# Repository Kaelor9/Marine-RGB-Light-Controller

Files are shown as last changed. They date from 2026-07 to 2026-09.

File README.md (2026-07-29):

<p align="center">
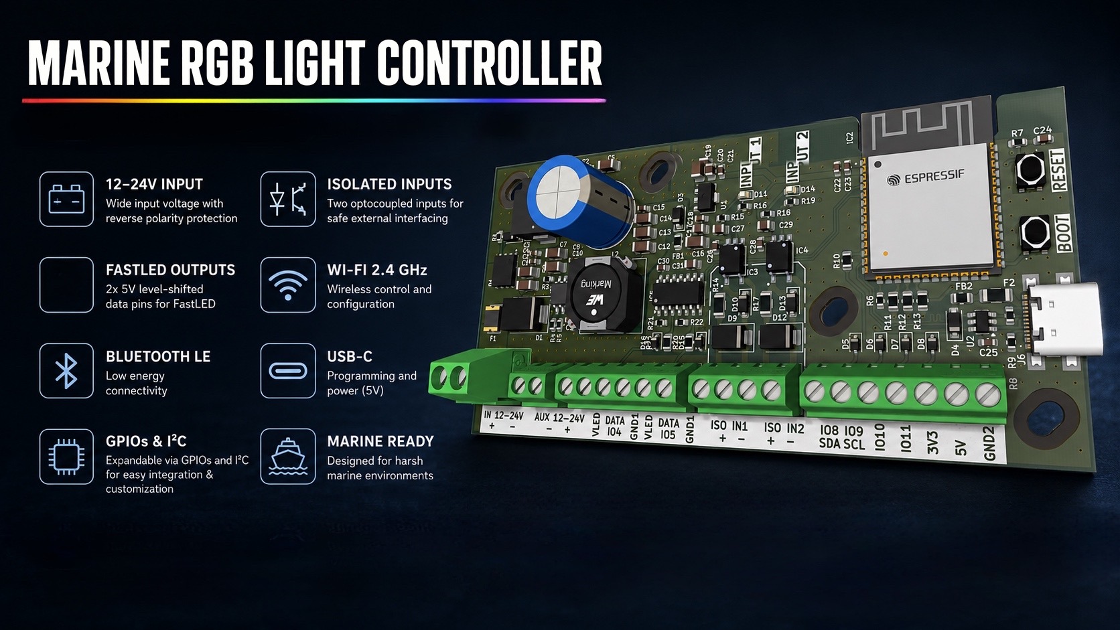
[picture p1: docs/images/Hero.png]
Marine RGB Light Controller
  
</p>

<h1 align="center">Marine RGB Light Controller</h1>

<p align="center">
  Professional ESP32-S3 controller for addressable RGB LED installations in marine, automotive and industrial environments.
</p>

<p align="center">
  
  
  
  
  
</p>

<p align="center">
  <a href="https://kaelor9.github.io/Marine-RGB-Light-Controller/">
    
  </a>
</p>

---

## About

The **Marine RGB Light Controller** is a custom-designed ESP32-S3 controller developed for reliable operation in demanding electrical environments.

Unlike generic ESP32 development boards, it integrates protected power electronics, optically isolated inputs, dual level-shifted LED outputs and dedicated expansion interfaces into a single compact PCB.

Originally designed for marine lighting systems, the controller is equally suited for automotive, off-road, RV, architectural and industrial LED installations.

---

## Why this controller?

Most ESP32 development boards are intended for prototyping and require additional external circuitry before they are suitable for real-world installations.

The Marine RGB Light Controller integrates the essential hardware needed for reliable field deployment:

- Protected 12–24V power input
- Reverse polarity protection
- TVS surge suppression
- Optically isolated inputs
- Dual 5V LED data outputs
- USB-C programming
- GPIO & I²C expansion
- Compact installation-ready PCB

This significantly reduces external wiring while improving robustness and long-term reliability.

---

## Key Features

- ⚡ Protected 12–24V DC controller input
- 🔋 Direct VIN pass-through LED power output
- 🌈 Two independent 5V level-shifted LED data outputs
- 🔒 Two high-speed optically isolated digital inputs
- 📡 Wi-Fi & Bluetooth LE
- 🔌 USB-C programming
- 🔧 GPIO & I²C expansion
- 🛡 TVS, fuse and reverse polarity protection
- ⚓ Designed for harsh electrical environments

---

## Applications

The controller is suitable for a wide range of professional LED installations, including:

- ⚓ Marine lighting
- 🚙 Automotive lighting
- 🏕 Camper & RV installations
- 🏭 Industrial automation
- 🏡 Architectural lighting
- 💡 Custom RGB LED projects

---

## Hardware

<p align="center">
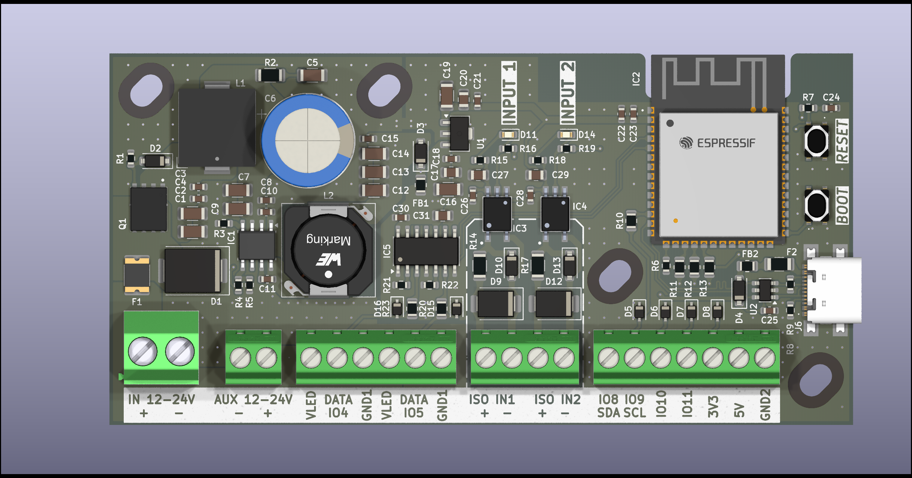
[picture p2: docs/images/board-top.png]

</p>

The PCB integrates everything required for a professional LED controller:

- ESP32-S3-WROOM-1-N8R8
- High-efficiency buck converter
- Low-noise 3.3V LDO
- USB-C programming interface
- Dual 5V level shifters
- High-speed optocouplers
- Protected controller power supply
- GPIO & I²C expansion
- Dedicated LED power distribution

---

## Technical Specifications

| Feature | Specification |
|---|---|
| MCU | ESP32-S3-WROOM-1-N8R8 |
| Flash | 8 MB |
| PSRAM | 8 MB |
| Input Voltage | 12–24V DC |
| Controller Protection | Fuse + Reverse Polarity + TVS |
| LED Supply | Direct VIN Pass-through |
| LED Outputs | 2 × 5V Logic (Level Shifted) |
| Digital Inputs | 2 × Optically Isolated |
| Wireless | Wi-Fi 2.4 GHz + Bluetooth LE |
| USB | USB-C |
| Expansion | GPIO + I²C |

---

## Pinout

<p align="center">
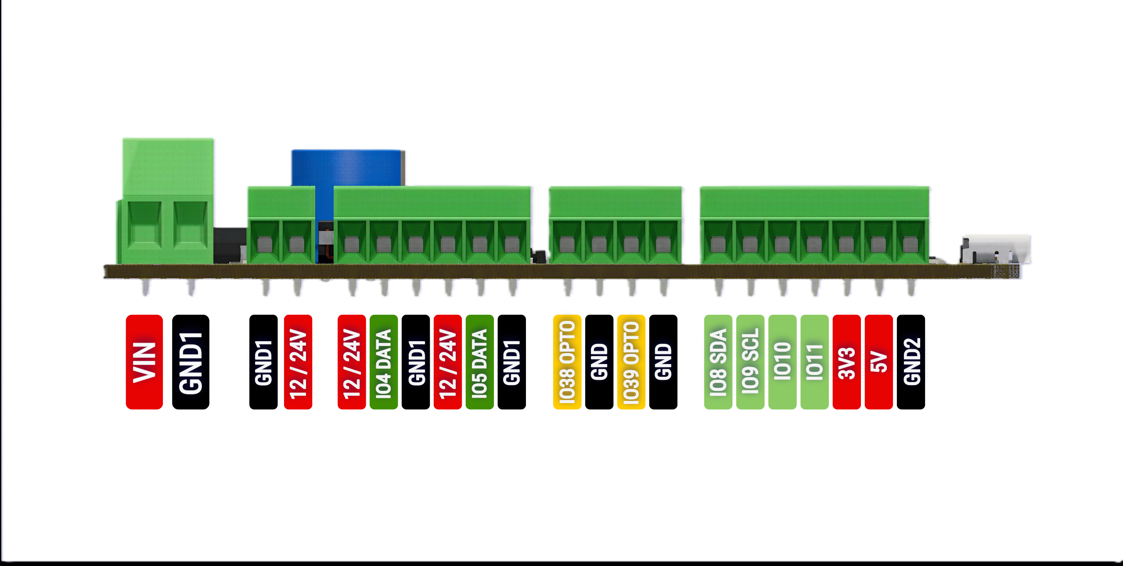
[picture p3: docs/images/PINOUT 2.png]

</p>

| Connection | Function |
|---|---|
| VIN | 12–24V DC Input |
| AUX Power | Direct VIN Pass-through |
| DATA 1 | 5V LED Data Output |
| DATA 2 | 5V LED Data Output |
| ISO IN1 | Optically Isolated Input |
| ISO IN2 | Optically Isolated Input |
| SDA / SCL | I²C Expansion |
| IO8 / IO9 | GPIO Expansion |
| IO10 / IO11 | GPIO Expansion |
| 3V3 | 3.3V Output |
| 5V | 5V Output |
| GND | Ground |

---

## Gallery

<p align="center">

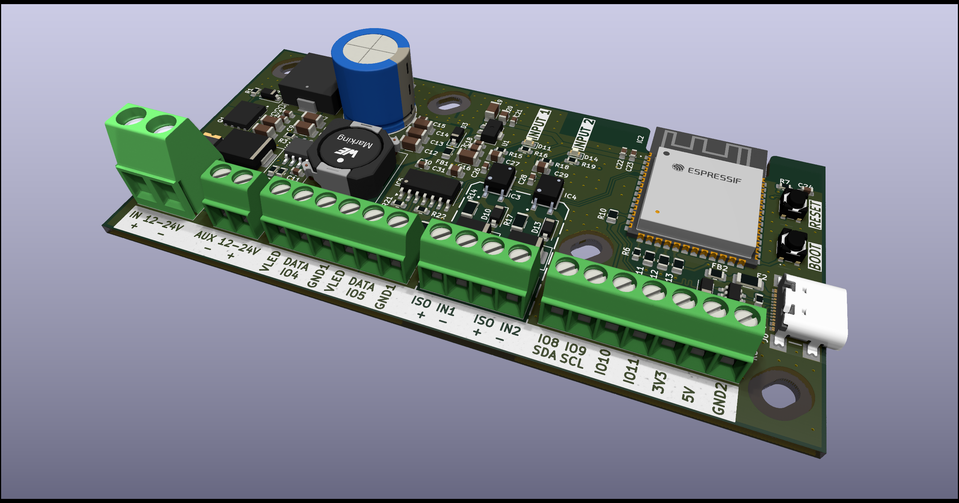
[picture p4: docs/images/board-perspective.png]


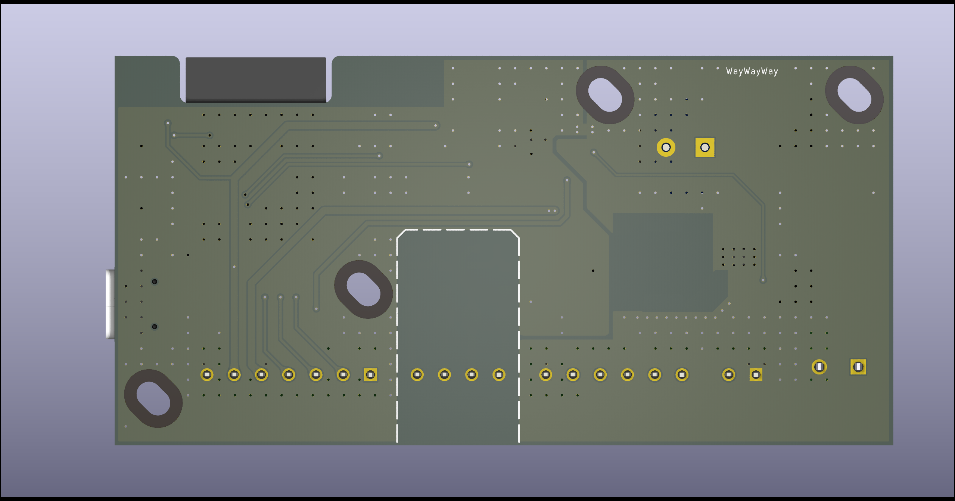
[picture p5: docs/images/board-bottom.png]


</p>

---

## Software

The firmware is developed for the ESP32-S3 using the Arduino framework and is designed around a modern, responsive web interface.

Configuration is performed directly from any web browser without requiring additional software. The modular firmware architecture allows new LED effects and features to be added easily.

Current and planned features include:

- Modern Web UI
- RGB Color Picker
- Brightness Control
- LED Effects
- Wi-Fi Configuration
- mDNS Support
- OTA Firmware Updates
- FastLED Support
- Configuration Storage

---

## Repository Structure

```text
.
├── docs/
│   ├── images/
│   ├── hardware.md
│   ├── software.md
│   └── fabrication.md
│
├── firmware/
│   └── Marine_RGB_Controller/
│
├── hardware/
│   ├── kicad/
│   ├── fabrication/
│   └── 3d/
│
├── site/
│
├── LICENSE
└── README.md
```

---

## Documentation

Project documentation is located inside the **docs** directory.

Available documentation includes:

- Hardware Design
- Power Supply
- LED Outputs
- Optically Isolated Inputs
- Pinout
- Firmware
- Fabrication
- Getting Started

---

## Important Information

> [!IMPORTANT]
>
> The **LED power output is a direct pass-through of the input supply voltage.**
>
> - LED VOUT = VIN
> - The LED supply is **not reverse polarity protected**
> - The LED supply is **not fused**
> - Only the controller electronics are protected by the onboard fuse, TVS diode and reverse polarity protection
> - External protection should be added where required by the installation

---

## Project Status

| Hardware | Firmware | Documentation |
|---|---|---|
| ✅ Revision 1 Complete | 🚧 In Development | 🚧 In Progress |

---

## Roadmap

### Hardware

- [x] Hardware Revision 1
- [x] Protected Power Supply
- [x] USB-C Programming
- [x] Dual LED Outputs
- [x] Optically Isolated Inputs

### Firmware

- [ ] Complete Web Interface
- [ ] OTA Updates
- [ ] MQTT Support
- [ ] Home Assistant Integration
- [ ] Additional LED Effects
- [ ] Configuration Backup & Restore

---

## License

This project is proprietary.

Copyright © 2026 Anders Merrild

All rights reserved.

No permission is granted to copy, modify, distribute, manufacture, publish, sublicense or use any part of this project without prior written permission from the copyright holder.

See the [LICENSE](LICENSE) file for full terms.

---

<p align="center">

Designed and developed by <strong>Kaelor9</strong>

<br>

ESP32 • Marine Electronics • Professional RGB Lighting Controller

</p>

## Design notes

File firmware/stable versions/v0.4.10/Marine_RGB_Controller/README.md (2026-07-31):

# Prism Firmware — v0.4.3

Firmware for the Marine RGB Light Controller hardware.

## Input configuration

The isolated input pins are fixed by the PCB:

- Input 1 = GPIO38
- Input 2 = GPIO39

Users do not enter GPIO numbers in the app. Under **Settings → Advanced settings**, both inputs can be enabled or disabled and assigned an action. Input enable changes take effect immediately.

Available actions include cycle preset colors, toggle power / hold to dim, next or previous effect, brightness up or down, warm white, and red, green or blue scenes.

## Light interface

- Embedded 6 × 60° perceptual hue wheel
- Hue-wheel selector remains fully inside the wheel
- Brightness slider integrated into the selected-color tile
- Static color, Rainbow Flow, Color Fade, Disco and Sparkle
- Smooth static transitions at approximately 60 FPS
- Warm-white compensation limited to the calibrated warm-white area

## Configuration notes

Changing LED count, color order or mDNS hostname requires a controller restart. Input enable settings apply immediately.

## Other included features

- Wi-Fi provisioning
- mDNS
- PWA name: Prism
- Embedded app logo
- OTA update page at `/update`

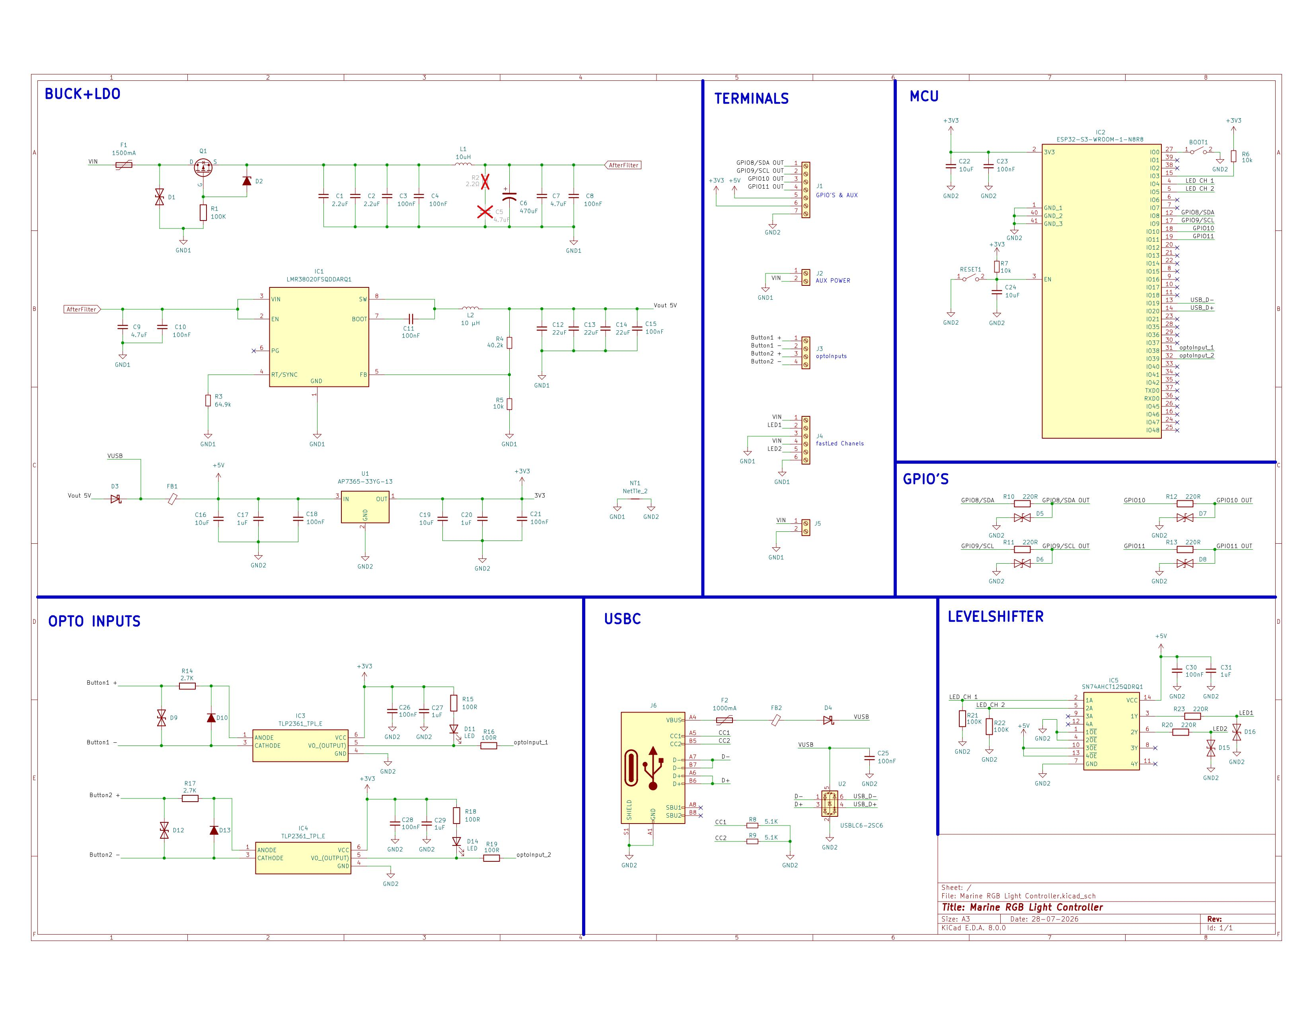
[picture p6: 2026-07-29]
docs/images/schematic.png

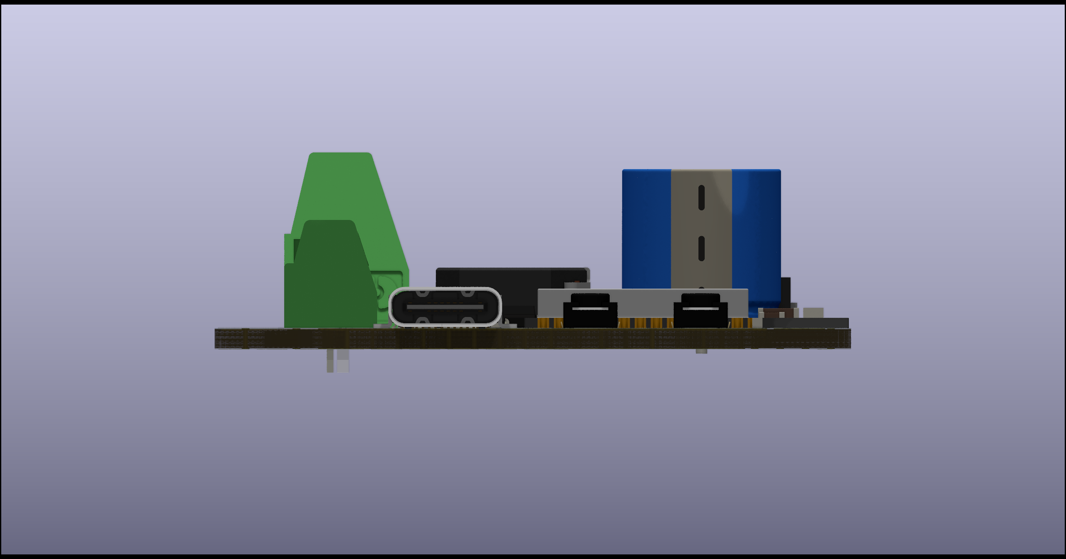
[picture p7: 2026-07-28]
docs/images/board-side-usb.png

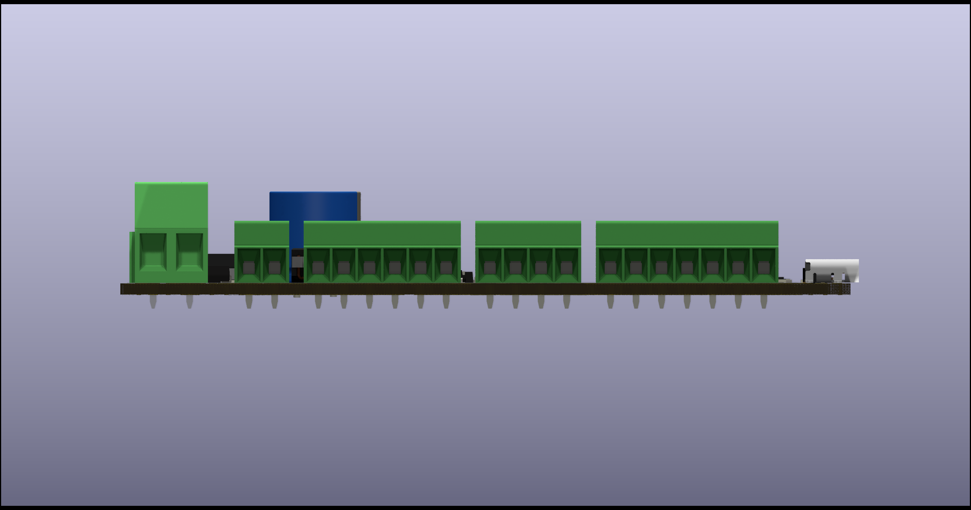
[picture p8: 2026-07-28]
docs/images/board-side-connectors.png

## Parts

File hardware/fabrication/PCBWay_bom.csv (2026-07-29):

Designator | Quantity | Value | Footprint | Package | MPN | DNP | Mount_Type | Description | Mfr. | Mfr. No: | Voltage Rating VDC | URL | Height | Mouser Part Number | Mouser Price/Stock | Manufacturer_Name | Mfr:
 | 1 |  |  |  |  |  | tht
BOOT, RESET | 2 | ~ | SW [PTS810SJM250SMTRLFS] |  |  |  | smt | Single Pole Single Throw (SPST) switch | PTS810SJM250SMTR LFS | C&K
C1, C2 | 2 | 2.2uF | C_1206_3216Metric |  |  |  | smt | Unpolarized capacitor, small symbol | Wurth Elektronik | 885012208124 | 100V
C10, C11, C15, C18, C21, C23, C25, C26, C28, C3, C30, C4, C8 | 13 | 100nF | C_0603_1608Metric |  |  |  | smt | [C4,C8]Unpolarized capacitor, small symbol; [C30]Multilayer Ceramic Capacitors MLCC - SMD/SMT 0603 MLCC X7R 0.1 uF, +/- 10% 50 V T&R MG | [C4,C8]Murata Electronics; [C30]Walsin | [C4,C8]GRM188R72A104KA35D; [C30]MG18B104K500CT | [C4,C8]100V; [C30]50V
C12, C13, C14 | 3 | 22uF | C_1206_3216Metric |  |  |  | smt | Multilayer Ceramic Capacitors MLCC - SMD/SMT PLEASE SEE SUGGESTED ALTERNATE MSASE105SC6105MFNA01 | TAIYO YUDEN | EMK316BB7226ML-T | 16V
C16, C19 | 2 | 10uF | C_1206_3216Metric |  |  |  | smt | Multilayer Ceramic Capacitors MLCC - SMD/SMT CGA 1206 16V 10uF X7R 10% AEC-Q200 | TDK | CGA5L1X7R1C106K160AC | 16V
C17, C20, C27, C29, C31 | 5 | 1uF | C_0805_2012Metric |  |  |  | smt | [C17,C20]Unpolarized capacitor, small symbol; [C27,C29]Multilayer Ceramic Capacitors MLCC - SMD/SMT KAM21KR71H105KL NEW GLOBAL PN 50V 1uF X7 A 581-KAM21KR71H105KL; [C31]Multilayer Ceramic Capacitors MLCC - SMD/SMT Automotive MLCC 1uF, 10%, X7R, 50VDC | [C17,C20]Samsung Electro-Mechanics; [C27,C29,C31]KYOCERA AVX | [C17,C20]CL21B105KAFNFNE; [C27,C29]08055C105K4T4A; [C31]KAM21KR71H105KL | [C17,C20]25V; [C27,C29,C31]50V
C22, C24 | 2 | 10uF | C_0603_1608Metric |  |  |  | smt | Multilayer Ceramic Capacitors MLCC - SMD/SMT 10 uF 35 VDC 20% 0603 X5R | Murata Electronics | GRM188R6YA106MA73D | 35V
C5 | 1 | 4.7uF | C_1206_3216Metric |  |  | Yes | smt | Unpolarized capacitor, small symbol | TDK | CGA5L1X7R2A475K160AC | 100V
C6 | 1 | 470uF | CP_Radial_D12.5mm_P5.00mm |  |  |  | tht | Aluminium Electrolytic Capacitors - Radial Leaded 470uF 63V 20% 12.5 x 25 | Vishay | MAL217058471E3 | 63V | https://www.mouser.dk/ProductDetail/Vishay -BC-Components/MAL217058471E3?qs=sGAEpiMZZ MvwFf0viD3Y3a3yb5D6sPUge%2FhbHmEvBGTt46%2F Okru66g%3D%3D
C7, C9 | 2 | 4.7uF | C_1206_3216Metric |  |  |  | smt | Unpolarized capacitor, small symbol | TDK | CGA5L1X7R2A475K160AC | 100V
D1 | 1 | D_TVS | D_SMC |  |  |  | smt | ESD Protection Diodes / TVS Diodes 33volts 5uA 28.1 Amps Uni-Dir | Bourns | SMCJ33A
D10, D13 | 2 | ~ | D_SOD-123 |  |  |  | smt | Small Signal Switching Diodes DIODE SWITCHING 100V 150mA 500mW SOD-123 | Comchip Technology | 1N4148W-HF
D11, D14 | 2 | LED | LED_0603_1608Metric |  |  |  | smt | Single Colour LEDs GREEN WATER CLEAR | Kingbright | APT1608SGC
D12, D9 | 2 | D_TVS | D_SMB |  |  |  | smt | ESD Protection Diodes / TVS Diodes 600W 33V 5% Bi-Directional | Littelfuse | SMBJ33CA
D15, D16, D5, D6, D7, D8 | 6 | SD05_SOD323 | D_SOD-323 |  |  |  | smt | ESD Protection Diodes / TVS Diodes 5V 450W 30A BiDirectional | Littelfuse | SD05C-01FTG
D2 | 1 | D_Zener_Filled | D_SOD-123 |  |  |  | smt | Zener diode, filled shape | Diodes Incorporated | BZT52C12-7-F
D3, D4 | 2 | D_Schottky | D_SOD-123 |  |  |  | smt | Schottky Diodes & Rectifiers RECT 40V 1A SM SCHOTTKY | Nexperia | PMEG40T10ERX
F1 | 1 | 1.5A | Fuse_1812_4532Metric |  |  |  | smt | Resettable Fuses - PPTC PTC RESETTABLE 0.75A 30V SMD 1812 | Bourns | MF-MSMF075/30-2 | 30 VDC | https://www.mouser.dk/ProductDetail/Bourns/MF-MSMF075-30-2?qs=3eVyCPG4fwndJ0FQwwSDlA%3D%3D
F2 | 1 | Polyfuse | Fuse_1206_3216Metric |  |  |  | smt | Resettable Fuses - PPTC 1206 Resettable SMD PPTC 0.50A/16V | Bourns | MF-NSMF050/16X-2
FB1 | 1 | BLM21PG600SN1D | R_0805_2012Metric |  |  |  | smt | Ferrite Beads 60 OHM 25% Alternate Sizing Guide Below | Murata Electronics | BLM21PG600SN1D
FB2 | 1 | FerriteBead_Small | R_0805_2012Metric |  |  |  | smt | Ferrite Beads 22 OHM 25% Alternate Sizing Guide Below | Murata Electronics | BLM21PG220SN1D
IC1 | 1 | C | Texas_R-PDSO-G8_EP2.95x4.9mm_Mask2.4x3.1mm |  |  |  | smt | Switching Voltage Regulators Automotive SIMPLE SWITCHER power converter 4.2-V to 80-V, 2-A, synchronous buck converter | Texas Instruments | LMR38020FSQDDARQ1 | 80V
IC2 | 1 | ESP32-S3-WROOM-1-N8R8 | ESP32S3WROOM1N8R8 |  | ESP32-S3-WROOM-1-N8R8 |  | smt | WiFi Modules - 802.11 (Engineering Samples Only) SMD Module, ESP32-S3R8 with 8 MB Octal PSRAM Die, 8 MB Quad SPI flash, PCB Antenna |  |  |  |  | 3.25 | 356-EP32S3WROOM1N8R8 | https://www.mouser.co.uk/ProductDetail/Espressif-Systems/ESP32-S3-WROOM-1-N8R8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 | Espressif Systems
IC3, IC4 | 2 | TLP2361_TPL,E | SOIC-6 |  | TLP2361(TPL,E |  | smt | High Speed Optocouplers X36 PB Photocoupler Lo I/P cur 125 degC |  |  |  |  |  | 757-TLP2361(TPLE | https://www.mouser.co.uk/ProductDetail/Toshiba/TLP2361TPLE?qs=HVbQlW5zcXUn%252BfokbzIatg%3D%3D | Toshiba
IC5 | 1 | SN74AHCT125QDRQ1 | SOIC-14_3.9x8.7mm_P1.27mm |  | SN74AHCT125QDRQ1 |  | smt | Automotive Catalog Quadruple Bus Buffer Gates With 3-State Outputs |  |  |  |  | 1.75 | 595-SN74AHCT125QDRQ1 | https://www.mouser.co.uk/ProductDetail/Texas-Instruments/SN74AHCT125QDRQ1?qs=zhgwDAIOVxtE5BLiD9k5oQ%3D%3D | Texas Instruments
J1 | 1 | Screw_Terminal_01x07 | Fixed Terminal Blocks 7P 3.5mm 90DEG |  |  |  | tht | Generic screw terminal, single row, 01x07, script generated (kicad-library-utils/schlib/autogen/connector/)
J2 | 1 | Screw_Terminal_01x02 | Fixed Terminal Blocks 2P 3.5mm 0DEG |  |  |  | tht | Generic screw terminal, single row, 01x02, script generated (kicad-library-utils/schlib/autogen/connector/)
J3 | 1 | Screw_Terminal_01x04 | Fixed Terminal Blocks 4P 3.5mm 90DEG |  |  |  | tht | Generic screw terminal, single row, 01x04, script generated (kicad-library-utils/schlib/autogen/connector/)
J4 | 1 | Screw_Terminal_01x06 | Fixed Terminal Blocks 6P 3.5mm 90DEG |  |  |  | tht | Generic screw terminal, single row, 01x06, script generated (kicad-library-utils/schlib/autogen/connector/)
J5 | 1 | Screw_Terminal_01x02 | 2_Position Screw Terminal 5mm Pitch |  |  |  | tht | Generic screw terminal, single row, 01x02, script generated (kicad-library-utils/schlib/autogen/connector/)
J6 | 1 | USB_C_Receptacle_USB2.0_16P | USB C [USB494000A] |  |  |  | tht | USB Connectors USB Type C, 2.0, 16P, Receptacle, Horizontal, Top Mount, SMT,T&R | GCT | USB4940-00-A
L1 | 1 | 10uH | L_Bourns_SRP1038C_10.0x10.0mm |  |  |  | smt | Power Inductors - SMD 10uH 20% SMD 1038 AEC-Q200 | Bourns | SRP1038A-100M
L2 | 1 | 10 µH | L_12x12mm_H6mm |  |  |  | smt | FIXED IND 10UH 5.8A 20 MOHM SMD |  | 7447706100 |  |  |  |  |  |  | Würth Elektronik
Q1 | 1 | PMOS | P-MOS [SI7141DPT1GE3] |  |  |  | smt | MOSFETs | Vishay Semiconductors | SI7469DP-T1-GE3 | 80V
R1, R21, R22 | 3 | 100K | R_0603_1608Metric |  |  |  | smt | Resistor | YAGEO | RC0603FR-07100KL
R10, R11, R12, R13, R20, R23 | 6 | 220R | R_0805_2012Metric |  |  |  | smt | Thick Film Resistors 1/4watts 220ohms 5% | KOA Speer | RK73B2ATTD221J | 150V
R14, R17 | 2 | 2.7K | R_1206_3216Metric |  |  |  | smt | Thick Film Resistors CRGH1206 1% 2K7 0.5W | TE Connectivity / Holsworthy | CRGH1206F2K7
R15, R18 | 2 | 2.2k | R_0603_1608Metric |  |  |  | smt | Thick Film Resistors 0603 Anti-sulfurated anti-surge resistor | Panasonic | ERJ-UP3J222V
R16, R19 | 2 | 100R | R_0603_1608Metric |  |  |  | smt
R2 | 1 | 2.2Ω | R_1206_3216Metric |  |  | Yes | smt | Thick Film Resistors - SMD 2.2ohms 1% 100ppm | Vishay / Dale | RCC12062R20FKEA | 200V
R3 | 1 | 64.9k | R_0603_1608Metric |  |  |  | smt | Thick Film Resistors 0603 64.9Kohm 1% Anti-Surge AEC-Q200 | Panasonic | ERJ-PA3F6492V | 150 V
R4 | 1 | 40.2k | R_0603_1608Metric |  |  |  | smt | Resistor, small symbol | Panasonic | ERJ-UP3F4022V | 150V
R5, R6, R7 | 3 | 10k | R_0603_1608Metric |  |  |  | smt | Resistor, small symbol | YAGEO | RC0603FR-07100KL
R8, R9 | 2 | 5.1K | R_0603_1608Metric |  |  |  | smt | Thick Film Resistors 0603 Anti-sulfurated anti-surge resistor | Panasonic | ERJ-UP3J512V | 150V
U1 | 1 | AP7365-33YG-13 | SOT-89-3 |  |  |  | smt | 3.3V, 1.5A, Low Noise, Fast Transient Response LDO Regulator, SOT-223
U2 | 1 | USBLC6-2SC6 | SOT-23-6 |  |  |  | smt | ESD Protection Diodes / TVS Diodes ESD Protection Low Cap | STMicroelectronics | USBLC6-2SC6

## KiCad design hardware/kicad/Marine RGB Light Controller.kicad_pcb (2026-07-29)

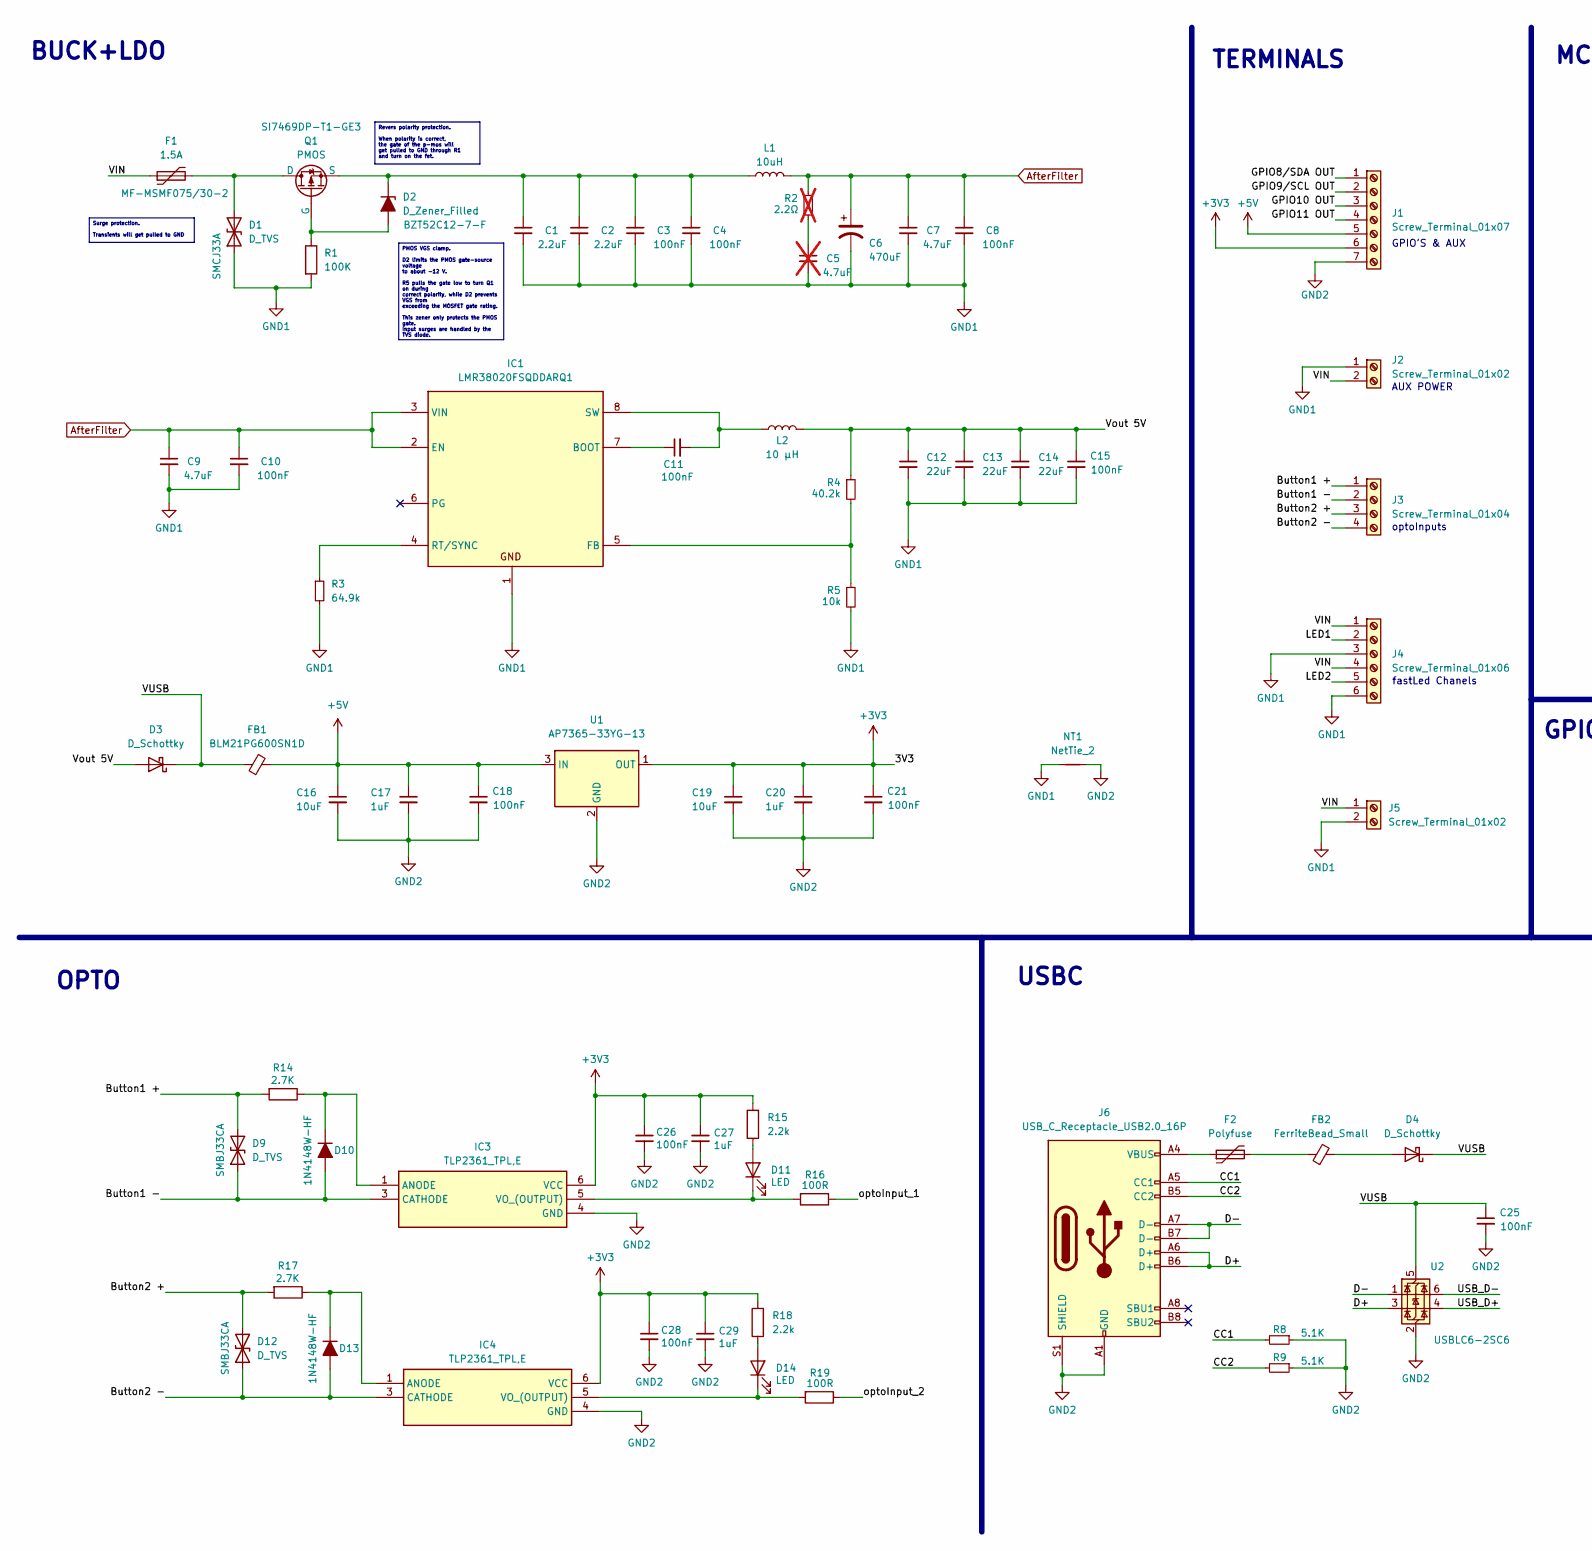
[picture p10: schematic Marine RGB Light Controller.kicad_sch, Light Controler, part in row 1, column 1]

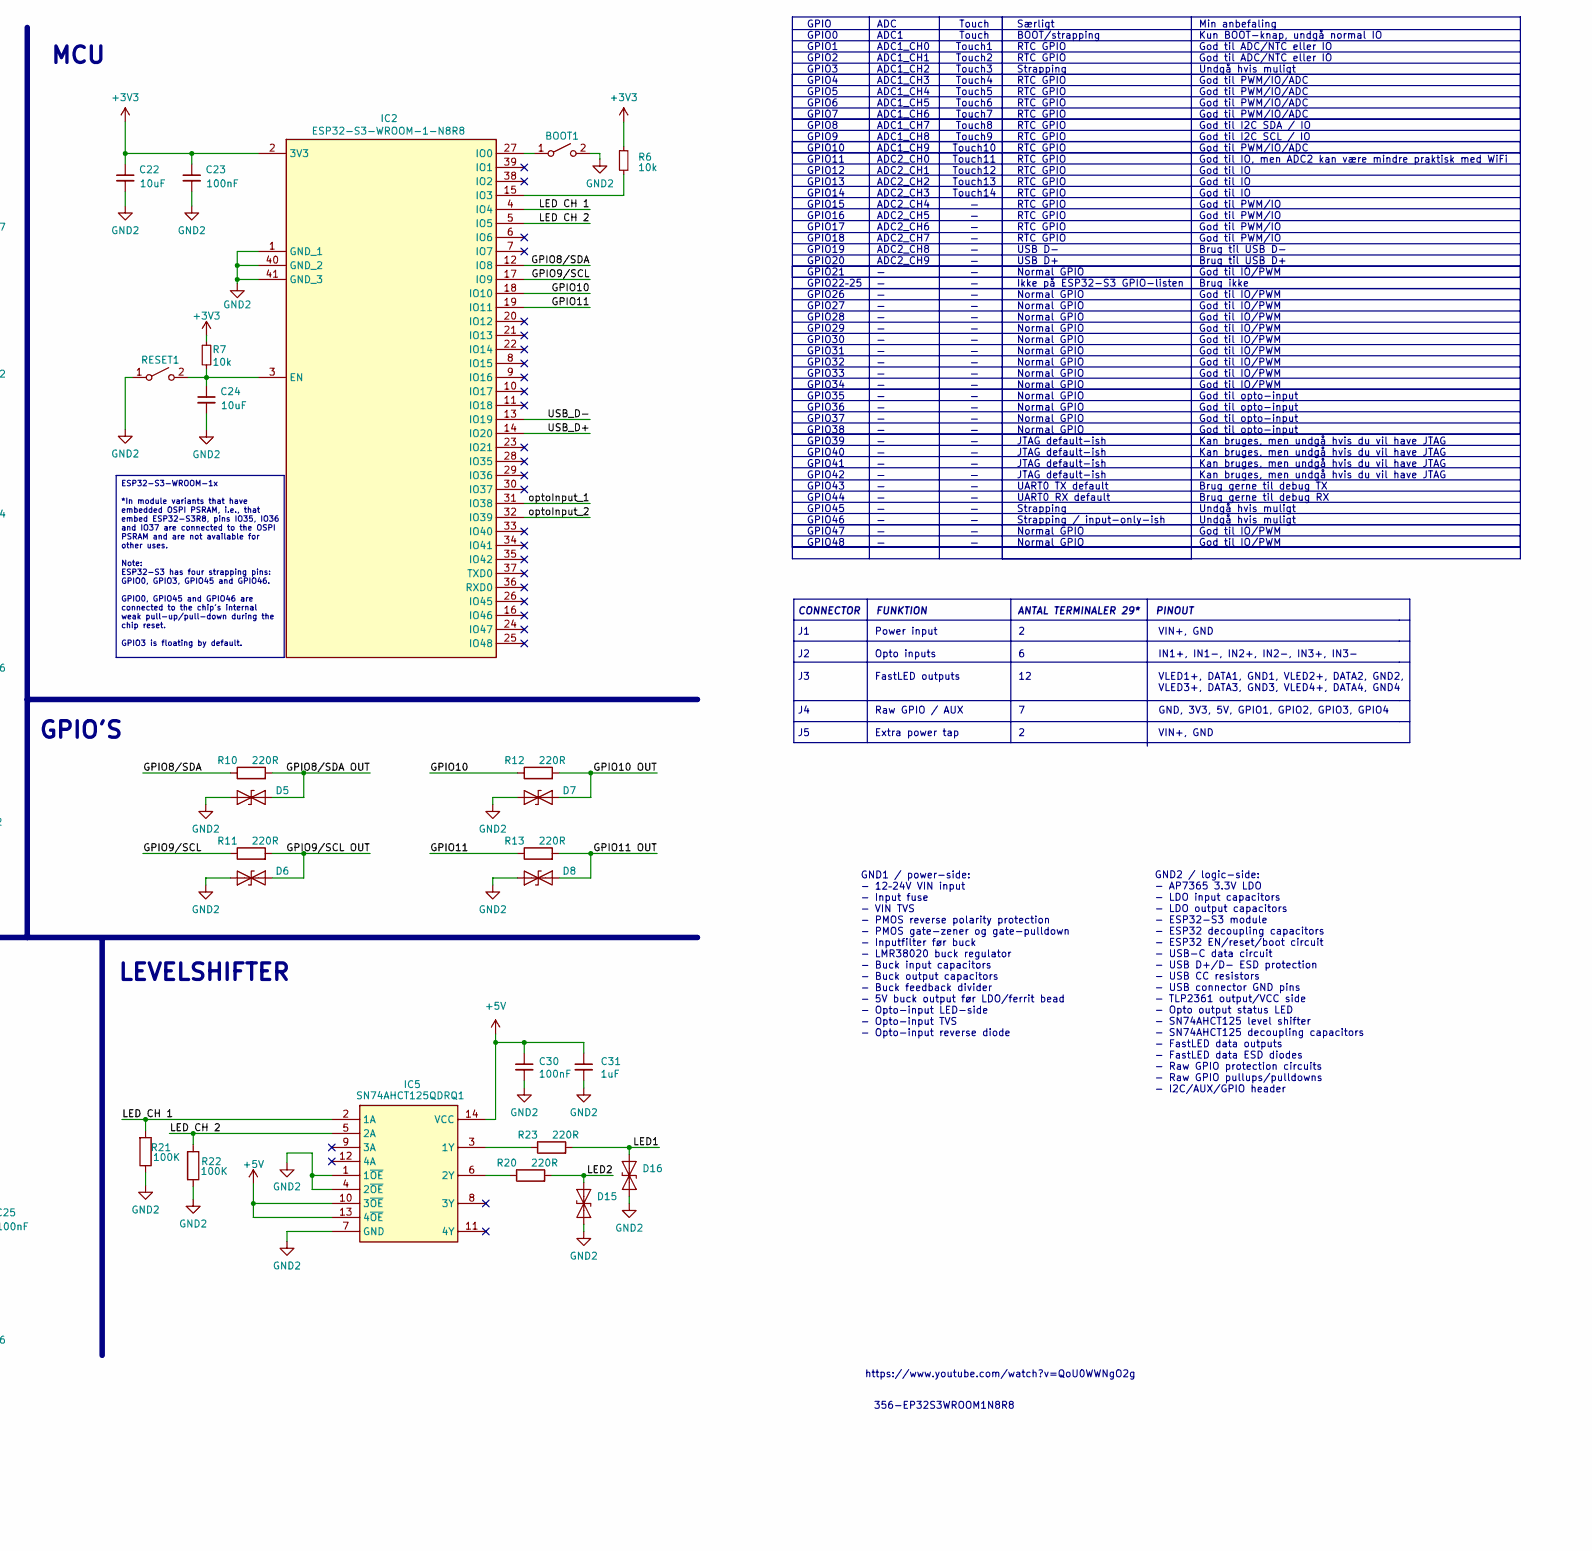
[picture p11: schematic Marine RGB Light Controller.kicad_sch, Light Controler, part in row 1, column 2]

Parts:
BOOT1: SW [PTS810SJM250SMTRLFS]
C1, C2: 2.2uF; C_1206_3216Metric; Voltage Rating VDC 100V
C3, C4, C8, C10: 100nF; C_0603_1608Metric; Voltage Rating VDC 100V
C5: 4.7uF; C_1206_3216Metric; Voltage Rating VDC 100V; not fitted
C6: 470uF; CP_Radial_D12.5mm_P5.00mm; Voltage Rating VDC 63V
C7, C9: 4.7uF; C_1206_3216Metric; Voltage Rating VDC 100V
C11, C15, C18, C21, C23, C25, C26, C28, C30: 100nF; C_0603_1608Metric; Voltage Rating VDC 50V
C12, C13, C14: 22uF; C_1206_3216Metric; Voltage Rating VDC 16V
C16, C19: 10uF; C_1206_3216Metric; Voltage Rating VDC 16V
C17, C20: 1uF; C_0805_2012Metric; Voltage Rating VDC 25V
C22, C24: 10uF; C_0603_1608Metric; Voltage Rating VDC 35V
C27, C29, C31: 1uF; C_0805_2012Metric; Voltage Rating VDC 50V
D1: D_TVS; D_SMC
D2: D_Zener_Filled; D_SOD-123
D3, D4: D_Schottky; D_SOD-123
D5, D6, D7, D8, D15, D16: SD05_SOD323; D_SOD-323
D9, D12: D_TVS; D_SMB
D10, D13: D_SOD-123
D11, D14: LED; LED_0603_1608Metric
F1: 1.5A; Fuse_1812_4532Metric; Voltage Rating VDC 30 VDC
F2: Polyfuse; Fuse_1206_3216Metric
FB1: BLM21PG600SN1D; R_0805_2012Metric
FB2: FerriteBead_Small; R_0805_2012Metric
IC1: LMR38020FSQDDARQ1; Texas_R-PDSO-G8_EP2.95x4.9mm_Mask2.4x3.1mm; Voltage Rating VDC 80V
IC2: ESP32-S3-WROOM-1-N8R8; ESP32S3WROOM1N8R8; Mouser Part Number 356-EP32S3WROOM1N8R8
IC3, IC4: TLP2361_TPL,E; SOIC-6; Mouser Part Number 757-TLP2361(TPLE
IC5: SN74AHCT125QDRQ1; SOIC-14_3.9x8.7mm_P1.27mm; Mouser Part Number 595-SN74AHCT125QDRQ1
J1: Screw_Terminal_01x07; Fixed Terminal Blocks 7P 3.5mm 90DEG
J2: Screw_Terminal_01x02; Fixed Terminal Blocks 2P 3.5mm 0DEG
J3: Screw_Terminal_01x04; Fixed Terminal Blocks 4P 3.5mm 90DEG
J4: Screw_Terminal_01x06; Fixed Terminal Blocks 6P 3.5mm 90DEG
J5: Screw_Terminal_01x02; 2_Position Screw Terminal 5mm Pitch
J6: USB_C_Receptacle_USB2.0_16P; USB C [USB494000A]
L1: 10uH; L_Bourns_SRP1038C_10.0x10.0mm
L2: 10 µH; L_12x12mm_H6mm
NT1: NetTie_2; NetTie-2_SMD_Pad0.5mm
Q1: PMOS; P-MOS [SI7141DPT1GE3]; Voltage Rating VDC 80V
R1, R21, R22: 100K; R_0603_1608Metric
R2: 2.2Ω; R_1206_3216Metric; Voltage Rating VDC 200V; not fitted
R3: 64.9k; R_0603_1608Metric; Voltage Rating VDC 150 V
R4: 40.2k; R_0603_1608Metric; Voltage Rating VDC 150V
R5, R6, R7: 10k; R_0603_1608Metric
R8, R9: 5.1K; R_0603_1608Metric; Voltage Rating VDC 150V
R10, R11, R12, R13, R20, R23: 220R; R_0805_2012Metric; Voltage Rating VDC 150V
R14, R17: 2.7K; R_1206_3216Metric
R15, R18: 2.2k; R_0603_1608Metric
R16, R19: 100R; R_0603_1608Metric
RESET1: SW [PTS810SJM250SMTRLFS]
U1: AP7365-33YG-13; SOT-89-3
U2: USBLC6-2SC6; SOT-23-6

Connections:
+3V3: C19.1, C20.1, C21.1, C22.1, C23.1, C26.1, C27.1, C28.1, C29.1, IC2.2 (3V3), IC3.6 (VCC), IC4.6 (VCC), J1.6, R6.1, R7.1, R15.2, R18.2, U1.1 (OUT)
+5V: C16.1, C17.1, C18.1, C30.1, C31.1, FB1.2, IC5.10 (3~OE), IC5.13 (4~OE), IC5.14 (VCC), J1.5, U1.3 (IN)
/Button1 +: D9.2 (A2), J3.1, R14.2
/Button1 -: D9.1 (A1), D10.2 (A), IC3.3 (CATHODE), J3.2
/Button2 +: D12.2 (A2), J3.3, R17.2
/Button2 -: D12.1 (A1), D13.2 (A), IC4.3 (CATHODE), J3.4
/CC1: J6.A5 (CC1), R8.2
/CC2: J6.B5 (CC2), R9.2
/D+: J6.A6 (D+), J6.B6 (D+), U2.3 (I/O2)
/D-: J6.A7 (D-), J6.B7 (D-), U2.1 (I/O1)
/GPIO8/SDA: IC2.12 (IO8), R10.1
/GPIO8/SDA OUT: D5.2 (A2), J1.1, R10.2
/GPIO9/SCL: IC2.17 (IO9), R11.1
/GPIO9/SCL OUT: D6.2 (A2), J1.2, R11.2
/GPIO10: IC2.18 (IO10), R12.1
/GPIO10 OUT: D7.2 (A2), J1.3, R12.2
/GPIO11: IC2.19 (IO11), R13.1
/GPIO11 OUT: D8.2 (A2), J1.4, R13.2
/LED1: D16.2 (A2), J4.2, R23.2
/LED2: D15.2 (A2), J4.5, R20.2
/LED CH 1: IC2.4 (IO4), IC5.2 (1A), R21.2
/LED CH 2: IC2.5 (IO5), IC5.5 (2A), R22.2
/USB_D+: IC2.14 (IO20), U2.4 (I/O2)
/USB_D-: IC2.13 (IO19), U2.6 (I/O1)
/VIN: F1.1, J2.2, J4.1, J4.4, J5.1
/VUSB: C25.1, D3.1 (K), D4.1 (K), FB1.1, U2.5 (VBUS)
/Vout 5V: C12.1, C13.1, C14.1, C15.1, D3.2 (A), L2.2, R4.1
/optoInput_1: IC2.31 (IO38), R16.1
/optoInput_2: IC2.32 (IO39), R19.1
AfterFilter: C6.1, C7.1, C8.1, C9.1, C10.1, IC1.2 (EN), IC1.3 (VIN), L1.2, R2.1
GND1: C1.2, C2.2, C3.2, C4.2, C5.2, C6.2, C7.2, C8.2, C9.2, C10.2, C12.2, C13.2, C14.2, C15.2, D1.1 (A1), IC1.1, IC1.9 (EP), J2.1, J4.3, J4.6, J5.2, NT1.1, R1.2, R3.2, R5.2; also elsewhere on the board
GND2: BOOT1.2 (B), C16.2, C17.2, C18.2, C19.2, C20.2, C21.2, C22.2, C23.2, C24.2, C25.2, C26.2, C27.2, C28.2, C29.2, C30.2, C31.2, D5.1 (A1), D6.1 (A1), D7.1 (A1), D8.1 (A1), D15.1 (A1), D16.1 (A1), IC2.1 (GND_1), IC2.40 (GND_2), IC2.41 (GND_3), IC2.42 (GND_4), IC2.43 (GND_5), IC2.44 (GND_6), IC2.45 (GND_7), IC2.46 (GND_8), IC2.47 (GND_9), IC2.48 (GND_10), IC2.49 (GND_11), IC3.4 (GND), IC4.4 (GND), IC5.1 (1~OE), IC5.4 (2~OE), IC5.7 (GND), J1.7, J6.A1 (GND), J6.A12 (GND), J6.B1 (GND), J6.B12 (GND), J6.S1 (SHIELD), NT1.2, R8.1, R9.1, R21.1, R22.1, RESET1.1 (A), U1.2 (GND), U2.2 (GND); also elsewhere on the board
unnamed 32: BOOT1.1 (A), IC2.27 (IO0); also elsewhere on the board
unnamed: C5.1, R2.2
unnamed: D1.2 (A2), F1.2, Q1.3 (D)
unnamed: D2.2 (A), Q1.2 (G), R1.1
unnamed: C1.1, C2.1, C3.1, C4.1, D2.1 (K), L1.1, Q1.1 (S)
unnamed: D4.2 (A), FB2.2
unnamed: D10.1 (K), IC3.1 (ANODE), R14.1
unnamed: D11.2 (A), R15.1
unnamed: D11.1 (K), IC3.5 (VO_(OUTPUT)), R16.2
unnamed: D13.1 (K), IC4.1 (ANODE), R17.1
unnamed: D14.2 (A), R18.1
unnamed: D14.1 (K), IC4.5 (VO_(OUTPUT)), R19.2
unnamed: F2.1, J6.A4 (VBUS), J6.A9 (VBUS), J6.B4 (VBUS), J6.B9 (VBUS)
unnamed: F2.2, FB2.1
unnamed: C11.1, IC1.7 (BOOT)
unnamed: IC1.5 (FB), R4.2, R5.1
unnamed: IC1.4 (RT/SYNC), R3.1
unnamed: C11.2, IC1.8 (SW), L2.1
unnamed 50: C24.1, IC2.3 (EN), R7.2, RESET1.2 (B); also elsewhere on the board
unnamed: IC2.15 (IO3), R6.2
unnamed: IC5.3 (1Y), R23.1
unnamed: IC5.6 (2Y), R20.1

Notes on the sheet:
ESP32-S3-WROOM-1x *In module variants that have embedded OSPI PSRAM, i.e., that embed ESP32-S3R8, pins IO35, IO36 and IO37 are connected to the OSPI PSRAM and are not available for other uses. Note: ESP32-S3 has four strapping pins: GPIO0, GPIO3, GPIO45 and GPIO46. GPIO0, GPIO45 and GPIO46 are conn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
PMOS VGS clamp. D2 limits the PMOS gate-source voltage to about -12 V. R5 pulls the gate low to turn Q1 on during correct polarity, while D2 prevents VGS from exceeding the MOSFET gate rating. This zener only protects the PMOS gate. Input surges are handled by the TVS diode.
Surge protection. Transients will get pulled to GND
Revers polarity protection. When polarity is correct, the gate of the p-mos will get pulled to GND through R1 and turn on the fet.
VIN+, GND IN1+, IN1-, IN2+, IN2-, IN3+, IN3- VLED1+, DATA1, GND1, VLED2+, DATA2, GND2, VLED3+, DATA3, GND3, VLED4+, DATA4, GND4 GND, 3V3, 5V, GPIO1, GPIO2, GPIO3, GPIO4 VIN+, GND
GND1 / power-side: - 12–24V VIN input - Input fuse - VIN TVS - PMOS reverse polarity protection - PMOS gate-zener og gate-pulldown - Inputfilter før buck - LMR38020 buck regulator - Buck input capacitors - Buck output capacitors - Buck feedback divider - 5V buck output før LDO/ferrit bead - Opto-in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
USBC
GPIO'S & AUX
CONNECTOR FUNKTION ANTAL TERMINALER 29* PINOUT
optoInputs
AUX POWER
2 6 12 7 2
Min anbefaling Kun BOOT-knap, undgå normal IO God til ADC/NTC eller IO God til ADC/NTC eller IO Undgå hvis muligt God til PWM/IO/ADC God til PWM/IO/ADC God til PWM/IO/ADC God til PWM/IO/ADC God til I2C SDA / IO God til I2C SCL / IO God til PWM/IO/ADC God til IO, men ADC2 kan være mindre praktisk me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
Touch Touch Touch1 Touch2 Touch3 Touch4 Touch5 Touch6 Touch7 Touch8 Touch9 Touch10 Touch11 Touch12 Touch13 Touch14 — — — — — — — — — — — — — — — — — — — — — — — — — — — — — — —
https://www.youtube.com/watch?v=QoU0WWNgO2g
OPTO
Power input Opto inputs FastLED outputs Raw GPIO / AUX Extra power tap
fastLed Chanels
Særligt BOOT/strapping RTC GPIO RTC GPIO Strapping RTC GPIO RTC GPIO RTC GPIO RTC GPIO RTC GPIO RTC GPIO RTC GPIO RTC GPIO RTC GPIO RTC GPIO RTC GPIO RTC GPIO RTC GPIO RTC GPIO RTC GPIO USB D- USB D+ Normal GPIO Ikke på ESP32-S3 GPIO-listen Normal GPIO Normal GPIO Normal GPIO Normal GPIO Normal GPI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
ADC ADC1 ADC1_CH0 ADC1_CH1 ADC1_CH2 ADC1_CH3 ADC1_CH4 ADC1_CH5 ADC1_CH6 ADC1_CH7 ADC1_CH8 ADC1_CH9 ADC2_CH0 ADC2_CH1 ADC2_CH2 ADC2_CH3 ADC2_CH4 ADC2_CH5 ADC2_CH6 ADC2_CH7 ADC2_CH8 ADC2_CH9 — — — — — — — — — — — — — — — — — — — — — — — — —
GND2 / logic-side: - AP7365 3.3V LDO - LDO input capacitors - LDO output capacitors - ESP32-S3 module - ESP32 decoupling capacitors - ESP32 EN/reset/boot circuit - USB-C data circuit - USB D+/D- ESD protection - USB CC resistors - USB connector GND pins - TLP2361 output/VCC side - Opto output statu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
TERMINALS
356-EP32S3WROOM1N8R8
BUCK+LDO
GPIO GPIO0 GPIO1 GPIO2 GPIO3 GPIO4 GPIO5 GPIO6 GPIO7 GPIO8 GPIO9 GPIO10 GPIO11 GPIO12 GPIO13 GPIO14 GPIO15 GPIO16 GPIO17 GPIO18 GPIO19 GPIO20 GPIO21 GPIO22–25 GPIO26 GPIO27 GPIO28 GPIO29 GPIO30 GPIO31 GPIO32 GPIO33 GPIO34 GPIO35 GPIO36 GPIO37 GPIO38 GPIO39 GPIO40 GPIO41 GPIO42 GPIO43 GPIO44 GPIO45 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
J1 J2 J3 J4 J5
LEVELSHIFTER
GPIO'S
MCU

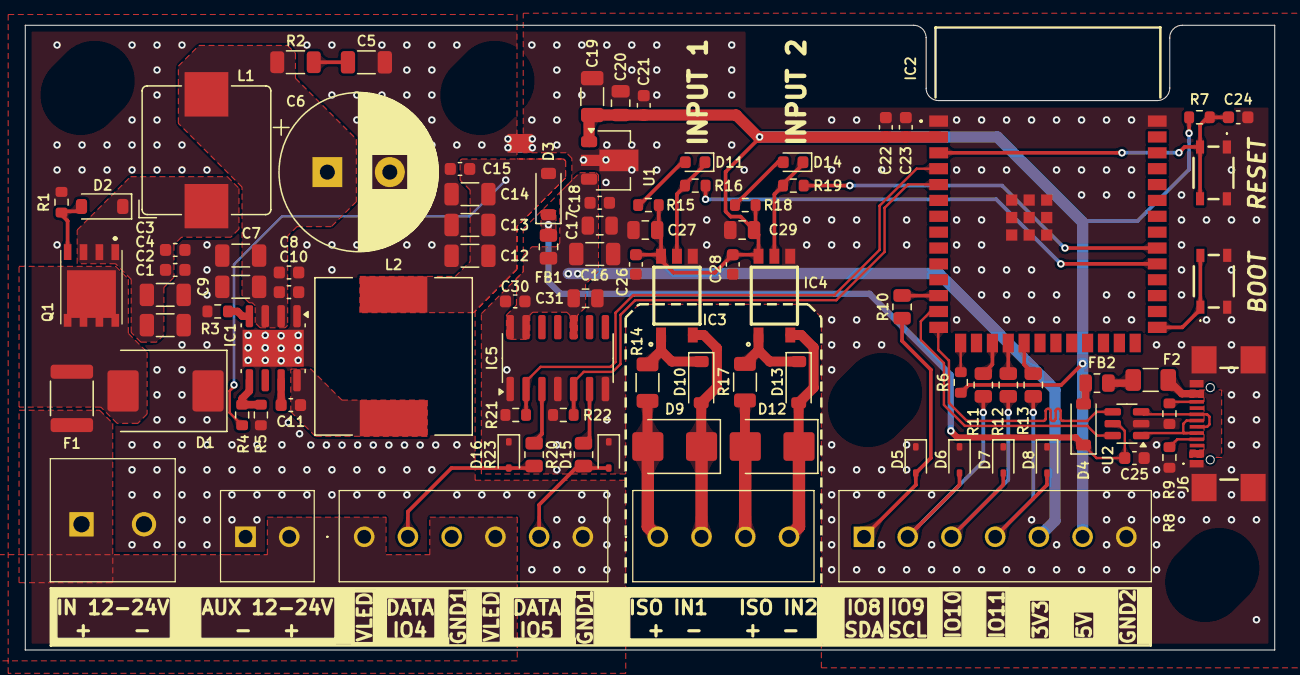
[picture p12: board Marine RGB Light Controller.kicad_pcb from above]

Board: 2 copper layers, 100.0 x 50.0 mm, 94 parts (1 on the bottom side), 54 nets.

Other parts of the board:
BOOT: SW [PTS810SJM250SMTRLFS]
NT1#2: NetTie_2; NetTie-2_SMD_Pad0.5mm
RESET: SW [PTS810SJM250SMTRLFS]

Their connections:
GND1: NT1#2.1; also elsewhere on the board
GND2: BOOT.2 (B), NT1#2.2, RESET.1 (A); also elsewhere on the board
unnamed 32: BOOT.1 (A); also elsewhere on the board
unnamed 50: RESET.2 (B); also elsewhere on the board

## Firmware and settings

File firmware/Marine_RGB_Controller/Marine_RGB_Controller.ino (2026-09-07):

#include <WiFi.h>
#include <WebServer.h>
#include <ESPmDNS.h>
#include <Preferences.h>
#include <FastLED.h>
#include <WiFiManager.h>
#include <HTTPUpdateServer.h>

#include "Config.h"
#include "WebUi.h"
#include "AppLogo.h"

enum class Effect : uint8_t { Static, Rainbow, ColorFade, Disco, Sparkle, Off };

// Only single-wire (clockless) chipsets are listed here. Clock-based parts such
// as APA102/SK9822 need a second output line and RGBW parts need a fourth
// channel, so neither can be driven correctly by the current Prism hardware.
enum class LedChipset : uint8_t {
  WS2811 = 0,
  WS2812,
  WS2812B,
  WS2813,
  WS2815,
  SK6812,
  APA104,
  UCS1903,
  UCS1903B
};

enum class ColorOrder : uint8_t { RGB = 0, RBG, GRB, GBR, BRG, BGR };

// Both defaults deliberately match firmware 0.4.x, so an existing installation
// behaves exactly the same after updating even though it has no stored value.
constexpr LedChipset DEFAULT_LED_CHIPSET = LedChipset::WS2811;
constexpr ColorOrder DEFAULT_COLOR_ORDER = ColorOrder::BRG;

enum class InputAction : uint8_t {
  CycleColors,
  TogglePower,
  NextEffect,
  PreviousEffect,
  BrightnessUp,
  BrightnessDown,
  WarmWhite,
  RedScene,
  GreenScene,
  BlueScene
};

struct RuntimeState {
  uint8_t r = 255;
  uint8_t g = 128;
  uint8_t b = 40;
  uint8_t brightness = 70;
  uint8_t speed = 50;
  uint8_t intensity = 65;
  bool power = true;
  Effect effect = Effect::Static;
};

struct Settings {
  String deviceName = DEFAULT_DEVICE_NAME;
  String mdnsName = DEFAULT_MDNS_NAME;
  uint16_t ledCount = DEFAULT_LED_COUNT;
  uint8_t maxBrightness = 100;
  ColorOrder colorOrder = DEFAULT_COLOR_ORDER;
  LedChipset chipset = DEFAULT_LED_CHIPSET;
  bool restoreState = true;
  bool smoothTransitions = true;
  bool warmCompensation = true;
  uint16_t defaultFade = 800;

  bool input1Enabled = true;
  bool input2Enabled = true;

  InputAction input1Action = InputAction::CycleColors;
  InputAction input2Action = InputAction::NextEffect;
};

struct DebouncedInput {
  int8_t pin = -1;
  uint8_t lastRaw = LOW;
  uint8_t stable = LOW;
  uint32_t changedAt = 0;
  uint32_t pressedAt = 0;
  uint32_t lastRepeatAt = 0;
  bool initialized = false;
  bool longPressActive = false;
  bool dimDirectionUp = true;
  bool ignoreUntilRelease = false;
};

CRGB leds[MAX_LED_COUNT];
uint16_t activeLedCount = DEFAULT_LED_COUNT;
WebServer server(80);
HTTPUpdateServer httpUpdater;
Preferences prefs;
RuntimeState state;
Settings settings;
DebouncedInput input1;
DebouncedInput input2;

bool stateDirty = false;
bool outputDirty = true;
uint32_t stateDirtyAt = 0;
uint32_t stateVersion = 1;

CRGB displayedColor = CRGB::Black;
CRGB transitionFrom = CRGB::Black;
CRGB transitionTo = CRGB::Black;
uint32_t transitionStartedAt = 0;
uint16_t transitionDuration = 0;
bool transitionActive = false;

// The web UI sends brightness targets live while the slider is moving. The
// physical output follows those targets through a short local smoothing stage,
// so network timing cannot turn a continuous finger gesture into visible steps.
// Q8 keeps sub-byte precision without using floating point in the render loop.
uint16_t displayedBrightnessQ8 = 0;
bool brightnessSmoothingInitialized = false;
uint32_t lastBrightnessSmoothingAt = 0;

uint8_t rainbowOffset = 0;
uint8_t fadeHue = 0;
uint32_t lastEffectFrame = 0;
uint32_t lastDiscoChange = 0;
CRGB discoColor = CRGB::Red;

const CRGB PRESET_COLORS[] = {
  CRGB(255, 0, 0),
  CRGB(0, 255, 0),
  CRGB(0, 0, 255),
  CRGB(255, 190, 0),
  CRGB(170, 0, 255),
  CRGB(0, 220, 190),
  CRGB(255, 128, 40),
  CRGB::Black
};
constexpr size_t PRESET_COLOR_COUNT = sizeof(PRESET_COLORS) / sizeof(PRESET_COLORS[0]);
size_t presetIndex = 0;

String jsonEscape(const String& value) {
  String result;
  result.reserve(value.length() + 8);
  for (size_t i = 0; i < value.length(); ++i) {
    const char c = value[i];
    if (c == '\\') result += "\\\\";
    else if (c == '"') result += "\\\"";
    else if (c == '\n') result += "\\n";
    else if (c == '\r') result += "\\r";
    else if (c == '\t') result += "\\t";
    else result += c;
  }
  return result;
}

uint8_t clampPercent(int value) {
  return static_cast<uint8_t>(constrain(value, 1, 100));
}

const char* effectName(Effect effect) {
  switch (effect) {
    case Effect::Static: return "static";
    case Effect::Rainbow: return "rainbow";
    case Effect::ColorFade: return "fade";
    case Effect::Disco: return "disco";
    case Effect::Sparkle: return "sparkle";
    case Effect::Off: return "off";
  }
  return "static";
}

// Returns false when the value is not a known effect, so the caller can keep
// the current one instead of silently falling back to Static.
bool parseEffect(const String& value, Effect& out) {
  for (uint8_t i = 0; i <= static_cast<uint8_t>(Effect::Off); ++i) {
    if (value == effectName(static_cast<Effect>(i))) {
      out = static_cast<Effect>(i);
      return true;
    }
  }
  return false;
}

const char* ledChipsetName(LedChipset chipset) {
  switch (chipset) {
    case LedChipset::WS2811: return "WS2811";
    case LedChipset::WS2812: return "WS2812";
    case LedChipset::WS2812B: return "WS2812B";
    case LedChipset::WS2813: return "WS2813";
    case LedChipset::WS2815: return "WS2815";
    case LedChipset::SK6812: return "SK6812";
    case LedChipset::APA104: return "APA104";
    case LedChipset::UCS1903: return "UCS1903";
    case LedChipset::UCS1903B: return "UCS1903B";
  }
  return "WS2811";
}

bool parseLedChipset(const String& value, LedChipset& out) {
  String candidate(value);
  candidate.trim();
  candidate.toUpperCase();
  for (uint8_t i = 0; i <= static_cast<uint8_t>(LedChipset::UCS1903B); ++i) {
    if (candidate == ledChipsetName(static_cast<LedChipset>(i))) {
      out = static_cast<LedChipset>(i);
      return true;
    }
  }
  return false;
}

const char* colorOrderName(ColorOrder order) {
  switch (order) {
    case ColorOrder::RGB: return "RGB";
    case ColorOrder::RBG: return "RBG";
    case ColorOrder::GRB: return "GRB";
    case ColorOrder::GBR: return "GBR";
    case ColorOrder::BRG: return "BRG";
    case ColorOrder::BGR: return "BGR";
  }
  return "BRG";
}

bool parseColorOrder(const String& value, ColorOrder& out) {
  String candidate(value);
  candidate.trim();
  candidate.toUpperCase();
  for (uint8_t i = 0; i <= static_cast<uint8_t>(ColorOrder::BGR); ++i) {
    if (candidate == colorOrderName(static_cast<ColorOrder>(i))) {
      out = static_cast<ColorOrder>(i);
      return true;
    }
  }
  return false;
}

// Reduces any input to a single RFC 1123 style hostname label: lowercase
// letters, digits and inner hyphens only. Separators collapse into one hyphen
// and the name never starts or ends with one. Falls back to the default when
// nothing usable is left, so mDNS can never be started with an invalid name.
String sanitizeHostname(const String& value) {
  String result;
  result.reserve(value.length() + 1);
  for (size_t i = 0; i < value.length(); ++i) {
    char c = value[i];
    if (c >= 'A' && c <= 'Z') c = static_cast<char>(c - 'A' + 'a');
    const bool allowed = (c >= 'a' && c <= 'z') || (c >= '0' && c <= '9');
    if (allowed) {
      result += c;
    } else if (result.length() > 0 && result[result.length() - 1] != '-') {
      result += '-';
    }
    if (result.length() >= MAX_HOSTNAME_LENGTH) break;
  }
  while (result.length() > 0 && result[result.length() - 1] == '-') {
    result.remove(result.length() - 1);
  }
  if (result.length() == 0) return String(DEFAULT_MDNS_NAME);
  return result;
}

// Strips control characters and enforces the length limit without cutting a
// multi-byte UTF-8 sequence in half, which would corrupt /api/state.
String sanitizeDeviceName(const String& value) {
  String result;
  result.reserve(value.length() + 1);
  for (size_t i = 0; i < value.length(); ++i) {
    const uint8_t c = static_cast<uint8_t>(value[i]);
    if (c < 0x20 || c == 0x7F) continue;
    const bool continuation = (c & 0xC0) == 0x80;
    if (result.length() >= MAX_DEVICE_NAME_LENGTH && !continuation) break;
    result += static_cast<char>(c);
  }
  result.trim();
  if (result.length() == 0) return String(DEFAULT_DEVICE_NAME);
  return result;
}

const char* inputActionName(InputAction action) {
  switch (action) {
    case InputAction::CycleColors: return "colors";
    case InputAction::TogglePower: return "power";
    case InputAction::NextEffect: return "effects";
    case InputAction::PreviousEffect: return "previous-effect";
    case InputAction::BrightnessUp: return "brightness-up";
    case InputAction::BrightnessDown: return "brightness-down";
    case InputAction::WarmWhite: return "warm-white";
    case InputAction::RedScene: return "red";
    case InputAction::GreenScene: return "green";
    case InputAction::BlueScene: return "blue";
  }
  return "colors";
}

bool parseInputAction(const String& value, InputAction& out) {
  for (uint8_t i = 0; i <= static_cast<uint8_t>(InputAction::BlueScene); ++i) {
    if (value == inputActionName(static_cast<InputAction>(i))) {
      out = static_cast<InputAction>(i);
      return true;
    }
  }
  return false;
}

void markStateChanged() {
  ++stateVersion;
  stateDirty = true;
  outputDirty = true;
  stateDirtyAt = millis();
}

void startStaticTransition(const CRGB& target) {
  transitionFrom = displayedColor;
  transitionTo = target;
  transitionStartedAt = millis();
  transitionDuration = settings.defaultFade;
  transitionActive = settings.smoothTransitions && transitionDuration > 0;
  if (!transitionActive) displayedColor = target;
}

void setStaticColor(uint8_t r, uint8_t g, uint8_t b) {
  state.r = r;
  state.g = g;
  state.b = b;
  state.effect = Effect::Static;
  state.power = true;
  startStaticTransition(CRGB(r, g, b));
  markStateChanged();
}

void setBrightness(int value) {
  state.brightness = clampPercent(value);
  state.power = true;
  if (state.effect == Effect::Off) state.effect = Effect::Static;
  markStateChanged();
}

void loadPreferences() {
  prefs.begin("marine-rgb", true);

  // Stored values are re-validated here as well. Preferences written by an
  // older firmware, a manual NVS edit or a partially failed write must never be
  // able to put the controller into an invalid state.
  settings.deviceName = sanitizeDeviceName(prefs.getString("device", DEFAULT_DEVICE_NAME));
  settings.mdnsName = sanitizeHostname(prefs.getString("mdns", DEFAULT_MDNS_NAME));
  settings.ledCount = constrain(prefs.getUShort("leds", DEFAULT_LED_COUNT), 1, MAX_LED_COUNT);
  settings.maxBrightness = constrain(prefs.getUChar("maxb", 100), 1, 100);

  settings.colorOrder = DEFAULT_COLOR_ORDER;
  parseColorOrder(prefs.getString("order", colorOrderName(DEFAULT_COLOR_ORDER)), settings.colorOrder);

  settings.chipset = DEFAULT_LED_CHIPSET;
  parseLedChipset(prefs.getString("chipset", ledChipsetName(DEFAULT_LED_CHIPSET)), settings.chipset);
  settings.restoreState = prefs.getBool("restore", true);
  settings.smoothTransitions = prefs.getBool("smooth", true);
  settings.warmCompensation = prefs.getBool("warmcomp", true);
  settings.defaultFade = constrain(prefs.getUShort("fade", 800), 0, 5000);

  settings.input1Enabled = prefs.getBool("in1en", true);
  settings.input2Enabled = prefs.getBool("in2en", true);

  const uint8_t input1Raw = prefs.getUChar("in1", static_cast<uint8_t>(InputAction::CycleColors));
  const uint8_t input2Raw = prefs.getUChar("in2", static_cast<uint8_t>(InputAction::NextEffect));
  settings.input1Action = input1Raw <= static_cast<uint8_t>(InputAction::BlueScene)
    ? static_cast<InputAction>(input1Raw)
    : InputAction::CycleColors;
  settings.input2Action = input2Raw <= static_cast<uint8_t>(InputAction::BlueScene)
    ? static_cast<InputAction>(input2Raw)
    : InputAction::NextEffect;

  if (settings.restoreState) {
    state.r = prefs.getUChar("r", 255);
    state.g = prefs.getUChar("g", 128);
    state.b = prefs.getUChar("b", 40);
    state.brightness = constrain(prefs.getUChar("bright", 70), 1, 100);
    state.speed = constrain(prefs.getUChar("speed", 50), 1, 100);
    state.intensity = constrain(prefs.getUChar("intens", 65), 1, 100);
    state.power = prefs.getBool("power", true);
    const uint8_t effectRaw = prefs.getUChar("effect", static_cast<uint8_t>(Effect::Static));
    state.effect = effectRaw <= static_cast<uint8_t>(Effect::Off)
      ? static_cast<Effect>(effectRaw)
      : Effect::Static;
  }

  prefs.end();
}

void savePreferences() {
  prefs.begin("marine-rgb", false);
  prefs.putString("device", settings.deviceName);
  prefs.putString("mdns", settings.mdnsName);
  prefs.putUShort("leds", settings.ledCount);
  prefs.putUChar("maxb", settings.maxBrightness);
  prefs.putString("order", colorOrderName(settings.colorOrder));
  prefs.putString("chipset", ledChipsetName(settings.chipset));
  prefs.putBool("restore", settings.restoreState);
  prefs.putBool("smooth", settings.smoothTransitions);
  prefs.putBool("warmcomp", settings.warmCompensation);
  prefs.putUShort("fade", settings.defaultFade);
  prefs.putBool("in1en", settings.input1Enabled);
  prefs.putBool("in2en", settings.input2Enabled);
  prefs.putUChar("in1", static_cast<uint8_t>(settings.input1Action));
  prefs.putUChar("in2", static_cast<uint8_t>(settings.input2Action));

  if (settings.restoreState) {
    prefs.putUChar("r", state.r);
    prefs.putUChar("g", state.g);
    prefs.putUChar("b", state.b);
    prefs.putUChar("bright", state.brightness);
    prefs.putUChar("speed", state.speed);
    prefs.putUChar("intens", state.intensity);
    prefs.putBool("power", state.power);
    prefs.putUChar("effect", static_cast<uint8_t>(state.effect));
  }

  prefs.end();
  stateDirty = false;
}

void configureInput(DebouncedInput& input, bool enabled, int8_t pin) {
  input = DebouncedInput{};
  input.pin = enabled ? pin : -1;
  if (input.pin >= 0) pinMode(input.pin, INPUT);
}

void configureInputs() {
  configureInput(input1, settings.input1Enabled, DEFAULT_ISO_INPUT_1_PIN);
  configureInput(input2, settings.input2Enabled, DEFAULT_ISO_INPUT_2_PIN);
}

// FastLED needs both the chipset and the colour order as compile-time template
// arguments, so every supported combination has to exist in the binary. The
// macro keeps that expansion in one place instead of 54 hand-written lines.
#define PRISM_ADD_LEDS(CHIPSET)                                                                      \
  switch (settings.colorOrder) {                                                                     \
    case ColorOrder::RGB: FastLED.addLeds<CHIPSET, LED_DATA_PIN_1, RGB>(leds, activeLedCount); break; \
    case ColorOrder::RBG: FastLED.addLeds<CHIPSET, LED_DATA_PIN_1, RBG>(leds, activeLedCount); break; \
    case ColorOrder::GRB: FastLED.addLeds<CHIPSET, LED_DATA_PIN_1, GRB>(leds, activeLedCount); break; \
    case ColorOrder::GBR: FastLED.addLeds<CHIPSET, LED_DATA_PIN_1, GBR>(leds, activeLedCount); break; \
    case ColorOrder::BGR: FastLED.addLeds<CHIPSET, LED_DATA_PIN_1, BGR>(leds, activeLedCount); break; \
    case ColorOrder::BRG:                                                                            \
    default: FastLED.addLeds<CHIPSET, LED_DATA_PIN_1, BRG>(leds, activeLedCount); break;              \
  }

void configureLedController() {
  // Re-clamped instead of trusted: activeLedCount indexes a fixed size buffer.
  activeLedCount = constrain(settings.ledCount, 1, MAX_LED_COUNT);

  switch (settings.chipset) {
    case LedChipset::WS2812: PRISM_ADD_LEDS(WS2812); break;
    case LedChipset::WS2812B: PRISM_ADD_LEDS(WS2812B); break;
    case LedChipset::WS2813: PRISM_ADD_LEDS(WS2813); break;
    case LedChipset::WS2815: PRISM_ADD_LEDS(WS2815); break;
    case LedChipset::SK6812: PRISM_ADD_LEDS(SK6812); break;
    case LedChipset::APA104: PRISM_ADD_LEDS(APA104); break;
    case LedChipset::UCS1903: PRISM_ADD_LEDS(UCS1903); break;
    case LedChipset::UCS1903B: PRISM_ADD_LEDS(UCS1903B); break;
    case LedChipset::WS2811:
    default: PRISM_ADD_LEDS(WS2811); break;
  }

  FastLED.setDither(true);
  FastLED.setCorrection(TypicalLEDStrip);
  FastLED.clear(true);
  displayedColor = CRGB(state.r, state.g, state.b);
}

uint16_t effectFrameInterval() {
  // Static colour fades should remain smooth regardless of the effect-speed slider.
  if (state.effect == Effect::Static) return 16;  // Approximately 60 FPS.
  return static_cast<uint16_t>(map(state.speed, 1, 100, 80, 10));
}

CRGB applyWarmCompensation(CRGB color) {
  if (!settings.warmCompensation || state.effect != Effect::Static) return color;

  // Keep the original conservative compensation window. It intentionally only
  // affects the established warm-white region, so ordinary red/orange/yellow
  // wheel colours are not re-balanced unexpectedly. Broader calibration should
  // be done against the physical LED strip rather than guessed in firmware.
  const bool warmWhiteSelected =
    state.r >= 200 &&
    state.g >= 90 && state.g <= 205 &&
    state.b <= 125 &&
    state.r > state.g &&
    state.g > state.b &&
    (state.r - state.g) >= 25 &&
    (state.g - state.b) >= 25;

  if (!warmWhiteSelected || state.brightness <= 20) return color;

  const uint8_t amount = static_cast<uint8_t>(
    map(state.brightness, 20, 100, 0, 255)
  );
  const uint8_t greenReduction = scale8(80, amount);
  const uint8_t blueReduction = scale8(135, amount);

  color.g = scale8_video(color.g, 255 - greenReduction);
  color.b = scale8_video(color.b, 255 - blueReduction);
  return color;
}

void renderStatic() {
  if (transitionActive) {
    const uint32_t elapsed = millis() - transitionStartedAt;
    if (elapsed >= transitionDuration) {
      displayedColor = transitionTo;
      transitionActive = false;
    } else {
      displayedColor = blend(transitionFrom, transitionTo, static_cast<uint8_t>((elapsed * 255UL) / transitionDuration));
    }
  } else {
    displayedColor = CRGB(state.r, state.g, state.b);
  }

  fill_solid(leds, activeLedCount, applyWarmCompensation(displayedColor));
}

void renderRainbow() {
  const uint8_t delta = max<uint8_t>(1, static_cast<uint8_t>(255 / activeLedCount));
  fill_rainbow(leds, activeLedCount, rainbowOffset, delta);
  rainbowOffset += map(state.speed, 1, 100, 1, 5);
}

void renderColorFade() {
  fill_solid(leds, activeLedCount, CHSV(fadeHue, 255, 255));
  fadeHue += map(state.speed, 1, 100, 1, 4);
}

void renderDisco() {
  const uint32_t interval = map(state.speed, 1, 100, 650, 90);
  if (millis() - lastDiscoChange >= interval) {
    lastDiscoChange = millis();
    discoColor = CHSV(random8(), 255, 255);
  }
  fill_solid(leds, activeLedCount, discoColor);
}

void renderSparkle() {
  CRGB base(state.r, state.g, state.b);
  base.nscale8_video(map(state.intensity, 1, 100, 35, 145));
  fill_solid(leds, activeLedCount, base);

  const uint8_t maxSparkles = activeLedCount >= 10 ? activeLedCount / 5 : 2;
  const uint8_t sparkles = map(state.intensity, 1, 100, 1, maxSparkles);
  for (uint8_t i = 0; i < sparkles; ++i) {
    if (random8() < map(state.speed, 1, 100, 35, 180)) {
      leds[random16(activeLedCount)] = blend(CRGB(state.r, state.g, state.b), CRGB::White, 190);
    }
  }
}

uint8_t targetOutputBrightness() {
  const uint8_t limitedPercent = static_cast<uint8_t>(
    (static_cast<uint16_t>(state.brightness) * settings.maxBrightness) / 100
  );
  return static_cast<uint8_t>(map(limitedPercent, 0, 100, 0, 255));
}

bool updateBrightnessSmoothing(uint32_t now) {
  const uint16_t targetQ8 = static_cast<uint16_t>(targetOutputBrightness()) << 8;

  if (!brightnessSmoothingInitialized) {
    displayedBrightnessQ8 = targetQ8;
    brightnessSmoothingInitialized = true;
    lastBrightnessSmoothingAt = now;
    return true;
  }

  const int32_t delta = static_cast<int32_t>(targetQ8) - displayedBrightnessQ8;
  if (delta == 0) {
    lastBrightnessSmoothingAt = now;
    return false;
  }

  // Time-based exponential tracking. A ~45 ms time constant intentionally
  // bridges the small gaps between successive HTTP targets instead of racing
  // all the way to each individual target and exposing the network cadence as
  // visible steps. It still tracks a moving finger closely. Q8 retains
  // sub-byte precision.
  uint32_t dt = now - lastBrightnessSmoothingAt;
  if (dt == 0) dt = 1;
  if (dt > 40) dt = 40; // Do not jump after a temporary Wi-Fi/main-loop stall.
  lastBrightnessSmoothingAt = now;

  constexpr uint16_t SMOOTHING_TAU_MS = 55;
  const uint32_t denominator = SMOOTHING_TAU_MS + dt;
  int32_t step = static_cast<int32_t>((static_cast<int64_t>(delta) * dt) / denominator);

  // Always make progress, and snap the final sub-byte once it is visually
  // indistinguishable. This prevents a long numerical tail around the target.
  if (step == 0) step = delta > 0 ? 1 : -1;
  if (abs(delta) <= 96 || abs(step) >= abs(delta)) {
    displayedBrightnessQ8 = targetQ8;
  } else {
    displayedBrightnessQ8 = static_cast<uint16_t>(
      static_cast<int32_t>(displayedBrightnessQ8) + step
    );
  }
  return true;
}
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
void loop() {
  server.handleClient();
  updateLeds();
  updateInput(input1, settings.input1Action);
  updateInput(input2, settings.input2Action);

  if (stateDirty && millis() - stateDirtyAt >= SETTINGS_SAVE_DELAY_MS) {
    savePreferences();
  }

  delay(1);
}

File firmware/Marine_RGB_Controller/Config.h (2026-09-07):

#pragma once
#include <Arduino.h>

constexpr uint8_t LED_DATA_PIN_1 = 4;

constexpr int8_t DEFAULT_ISO_INPUT_1_PIN = 38;
constexpr int8_t DEFAULT_ISO_INPUT_2_PIN = 39;

constexpr uint8_t ISO_INPUT_ACTIVE_LEVEL = HIGH;

constexpr uint16_t DEFAULT_LED_COUNT = 300;
constexpr uint16_t MAX_LED_COUNT = 300;

constexpr char DEFAULT_DEVICE_NAME[] = "Prism";
constexpr char DEFAULT_MDNS_NAME[] = "prism";
constexpr char WIFI_SETUP_AP_NAME[] = "Prism Setup";

constexpr uint8_t MAX_DEVICE_NAME_LENGTH = 31;
// Kept well below the 63 character DNS label limit; long .local names are
// awkward to type and some clients truncate them anyway.
constexpr uint8_t MAX_HOSTNAME_LENGTH = 24;

constexpr uint16_t WIFI_SETUP_TIMEOUT_SECONDS = 300;
constexpr uint32_t INPUT_DEBOUNCE_MS = 45;
constexpr uint32_t INPUT_LONG_PRESS_MS = 550;
constexpr uint32_t INPUT_DIM_STEP_MS = 90;
constexpr uint32_t SETTINGS_SAVE_DELAY_MS = 900;

// Single source of truth for the version. The web interface in WebUi.h is
// compiled into this firmware, so it reports this value instead of carrying a
// version string of its own. Keep site/manifest.json in sync when releasing.
constexpr char FIRMWARE_VERSION[] = "0.5.6";

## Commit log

2026-07-29 Add schematic image to README
2026-07-29 Remove schematic image from README
    Removed schematic image from README.
2026-07-29 file structure fixes
    [Marine RGB Light Controller.kicad_pcb, Marine RGB Light Controller.kicad_sch, PCBWay_bom.csv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]
2026-07-29 Update print statement from 'Hello' to 'Goodbye'
2026-07-30 Add new firmware with web UI, effects and advanced settings
    - Add hue wheel and live color control
    - Add brightness and transition settings
    - Add Rainbow Flow, Color Fade, Disco and Sparkle effects
    - Add Wi-Fi setup, mDNS and OTA update support
    - Add persistent settings and configurable isolated inputs
2026-07-30 new hue wheel
2026-07-31 new firmware bugs and fixes
    [Config.h]
2026-09-07 Prism v0.5.1 build fix
    [Marine_RGB_Controller.ino]
2026-09-07 Prism v0.5.5 Aurora captive portal fix
    [Config.h, Marine_RGB_Controller.ino]
2026-09-07 Prism v0.5.6 softAP fixes
    [Config.h, Marine_RGB_Controller.ino]

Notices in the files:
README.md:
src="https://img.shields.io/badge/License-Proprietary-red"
